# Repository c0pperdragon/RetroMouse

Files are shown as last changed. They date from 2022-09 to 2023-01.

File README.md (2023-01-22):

# RetroMouse
Adapter to attach PS/2 compatible mice to retro computers

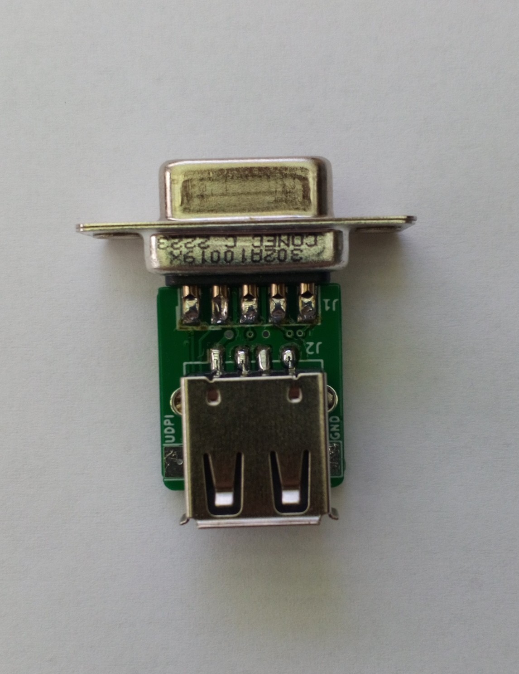
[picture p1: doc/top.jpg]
Top view


## Motivation

I wanted to try to make such an adapter using one attiny1604 microcontroller 
with only the minimum additional circuitry.
This part also was one of the few that mouser actually had in stock.

## Mouse compatibility

The USB socket suggests that any USB mouse can be used, but that is actually not true. In 
reality the adapter only supports the simpler PS/2 interface protocol which can be handled by
regular microcontrollers just well.

For this to work, the mouse must be able to optionally support PS/2 if needed. Luckily this
compatibility is present in quite many devices, especially in the cheap and simple variants.
Unluckily on the other hand, this compatibilty depends on the specific controller IC the
manufacturer used for the mouse and can not really be guessed from the outside.
When PS/2 compatibility is not directly advertised, the only thing to do is just try.

## Arduino development

The microcontroller is supported by the Arduino IDE (using the megaTinyCore add-on).
To modify the firmware, you need a programmer device to re-flash the microcontroller
using the UDPI pin. Details on this process are available on the megaTinyCore webpage.

## Compatibility

This adapter works with Amiga and C64 computers and can auto-detect the host machine.
Further machines (for example Atari ST) may be supported in the future. 

## C64 input modes

From power-up, the adapter emulates the Commodore 1351 mouse. If you want to 
emulate a pair of paddles instead (to play Arkanoid, for example) hold down the right mouse button 
and click the left button 5 times. Doing the same thing with 6 left clicks switches back
to standard mode.

## Attention! No Hot-Plugging

The adapter is not designed to be hot-plugged into the host machine or the mouse to be hot-plugged
into the adapter. Make sure to always power down the host when changing configuration.

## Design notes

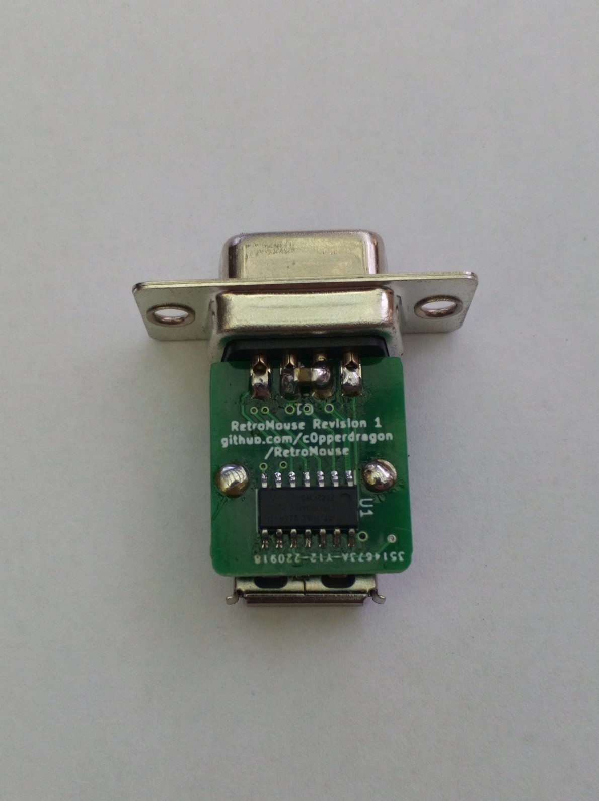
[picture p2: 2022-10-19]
doc/bottom.jpg

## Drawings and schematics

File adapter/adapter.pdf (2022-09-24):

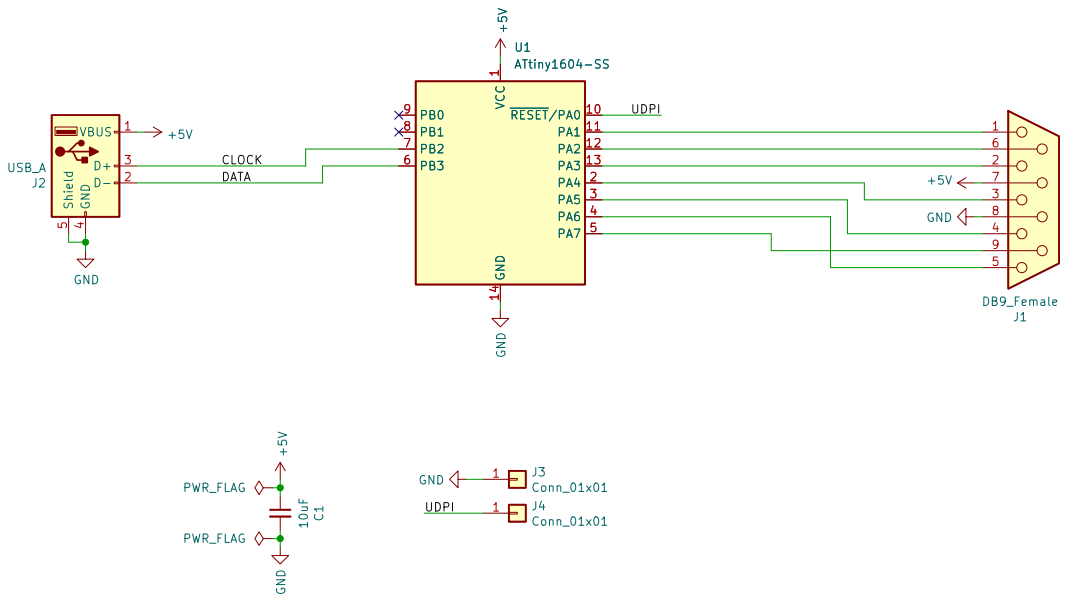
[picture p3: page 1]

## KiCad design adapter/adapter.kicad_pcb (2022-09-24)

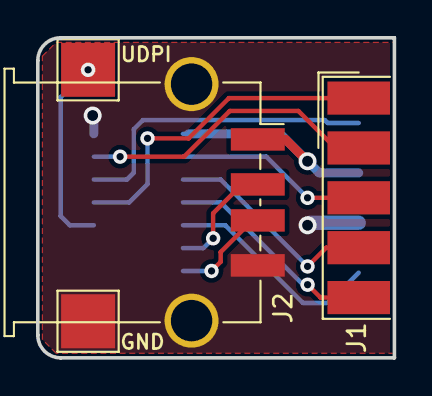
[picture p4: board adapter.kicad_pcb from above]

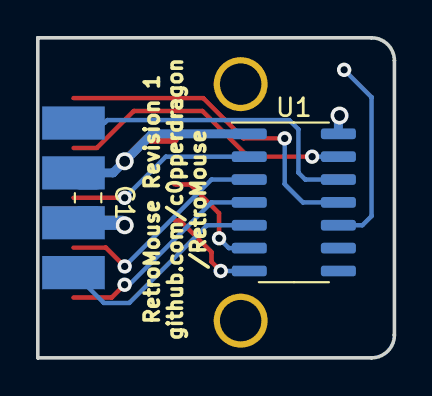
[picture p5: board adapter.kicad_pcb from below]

Board: 2 copper layers, 19.8 x 17.8 mm, 6 parts (2 on the bottom side), 12 nets.

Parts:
C1: 10uF; C_0805_2012Metric_Pad1.18x1.45mm_HandSolder
J1: DB9_Female; DSUB-9_Female_EdgeMount_P2.77mm
J2: USB_A; USB_A_TE_292303-7_Horizontal
J3, J4: Conn_01x01; TestPoint_Pad_3.0x3.0mm
U1: ATtiny1604-SS; SOIC-14_3.9x8.7mm_P1.27mm

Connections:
+5V: C1.1, J1.7, J2.1 (VBUS), U1.1 (VCC)
/CLOCK: J2.3 (D+), U1.7 (PB2)
/DATA: J2.2 (D-), U1.6 (PB3)
/UDPI: J4.1, U1.10 (~RESET/PA0)
GND: C1.2, J1.8, J2.4 (GND), J2.5 (Shield), J3.1, U1.14 (GND)
unnamed: J1.1, U1.11 (PA1)
unnamed: J1.2, U1.13 (PA3)
unnamed: J1.3, U1.2 (PA4)
unnamed: J1.4, U1.3 (PA5)
unnamed: J1.5, U1.4 (PA6)
unnamed: J1.6, U1.12 (PA2)
unnamed: J1.9, U1.5 (PA7)

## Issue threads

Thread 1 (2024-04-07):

How to build?

hjf, 2024-04-07:
Hello. I built the circuit like in the PDF file, and burned an attiny1614 (i don't have a 1604 but it seems it should still work).

I used megatinycore and set it to 16mhz, millis/micros disabled.

Unfortunately it doesn't seem to work when connected to a C64 with GEOS (configured for 1351 mouse). There is some random movement at times but it's completely random, the pointer is mostly still.

I've also downgraded megatinycore to 2.6.1 which was the latest version when this repo was updated but no luck either.

Am I missing something? I've checked the PS/2 lines and I don't see a constant stream of data, just some sporadic bursts of pulses. The mouse is a 1999 vintage Intellimouse Explorer which came with a USB to PS2 adapter so I know it should be compatible with PS2 (i've also tried other mice), so I'm thinking it could be related to build options.

c0pperdragon, 2024-04-07:
I don't remember much from the project any more. But finding a compatible mouse was actually quite a problem. I had best success with the cheapest USB mice as they seem to use quite an old PS2/USB compatible chip with just the bare minimum functionality. But it is really hit&miss there.

hjf, 2024-04-07:
OK, so I found an actual PS/2 mouse (Genius),... and it didn't work either.

So I tried changing the settings. It seems 8MHz is the right speed. I've noticed that the PS/2 lines have activity with this setting, but ONLY with the Intellimouse, not with the PS/2 mouse.

When connected to the C64, the mouse can click (WOO!!), but it doesn't move (aww). So I chased it to the upstream library for the mouse: https://github.com/getis/Arduino-PS2-Mouse-Handler/issues/1. The workaround in that issue didn't work for me either.

The TLDR of this is: may or may not work. Confirmed working is HP 600553-002 Optical Scrolling.

c0pperdragon, 2024-04-07:
For more troubleshooting you could try to power the adapter not from the C64 but directly from 5V (see schematics where to connect power). It would then go to Amiga mode when it does not detect the C64s polling. There you can better see on an oscilloscope what the mouse emulation intends to do.
The Amiga mouse directly puts the 2 signals of each of the 2 rotary decoders on 4 output pins. Also the mouse buttons are direcly available on the DSUB-9 connector:
X-Axis: pin 2 & pin 4
Y-Axis: pin 1 & pin 1
button 1-3: Pin  6, pin 5, pin 9

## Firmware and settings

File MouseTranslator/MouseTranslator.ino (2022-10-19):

// Target controller:  
//   attiny1604 with 16mhz
//   Disabled millis()/micros() to avoid timing glitches and free timer A
//   setup time 0 ms

#include "PS2MouseHandler.h"

#define DEBUG       PIN_PB1
#define MOUSE_DATA  PIN_PB3
#define MOUSE_CLOCK PIN_PB2
                                 // C64      Amiga mouse
#define SUBD_PIN1   PIN_PA1      // up       mouse v
#define SUBD_PIN2   PIN_PA3      // down     mouse h
#define SUBD_PIN3   PIN_PA4      // left     mouse vq
#define SUBD_PIN4   PIN_PA5      // right    mouse hq
#define SUBD_PIN5   PIN_PA6      // pot y    middle button
#define SUBD_PIN6   PIN_PA2      // button   left buttonm
#define SUBD_PIN9   PIN_PA7      // pot x    right button

#define MODE_AMIGA    1
#define MODE_C64      2
#define MODE_ATARI    3
byte mode;

PS2MouseHandler mouse(MOUSE_CLOCK, MOUSE_DATA);
unsigned int x;
unsigned int y;



// ------ low-level subd pin handling ---------
bool countedges;
unsigned int edgecounter;
unsigned int edgeseparation;

// set pin to either low (when active) or having a weak pullup
void set_subd(byte pin, bool active)
{
    if (active) 
    {
        digitalWrite(pin, LOW);  
        pinMode(pin, OUTPUT);
    }
    else
    {
        pinMode(pin, INPUT_PULLUP);
    }
}
void init_subd(bool emulate_pots, bool count)
{
    set_subd(SUBD_PIN1, false);
    set_subd(SUBD_PIN2, false);
    set_subd(SUBD_PIN3, false);
    set_subd(SUBD_PIN4, false);
    set_subd(SUBD_PIN5, false);
    set_subd(SUBD_PIN6, false);
    set_subd(SUBD_PIN9, false);
    AC0.INTCTRL = 0x00;          // disable AC interrupt       
    TCA0.SINGLE.INTCTRL = 0x00;  // disable TCA0 interrupts

    TCA0.SINGLE.CTRLA = 0x01;          // enable timer at full speed
    TCA0.SINGLE.CTRLB = 0x00;          // normal counting mode
    TCA0.SINGLE.CTRLC = 0x00;          // no timer output on pins
    TCA0.SINGLE.CTRLD = 0x00;          // disable split mode (use single mode)
    TCA0.SINGLE.CTRLECLR = 0x03;       // normal register update, counting up
    TCA0.SINGLE.EVCTRL = 0x00;         // no event couting                
    TCA0.SINGLE.CNT = 0;
    TCA0.SINGLE.PER = 0xffff;
    TCA0.SINGLE.CMP0 = 0xffff;
    TCA0.SINGLE.CMP1 = 0xffff;
    if (emulate_pots)
    {
        countedges = false;        
        TCA0.SINGLE.INTCTRL = 0x30;        // enable compare interrupt on cannels 0 & 1 
    }
    else if (count)
    {
        countedges = true;
    }
    if (emulate_pots || count)
    {
        VREF.CTRLA = 0x00;         // use 0.55V as VREF for the AC
        AC0.MUXCTRLA = 0x02;       // compare PA7 against voltage reference
        AC0.CTRLA = 0x27;          // trigger at negative edge, maximum hysteresis
        AC0.INTCTRL = 0x01;        // enable AC interrupt 
    }    
}
void set_pots(unsigned int x, unsigned int y)
{
    TCA0.SINGLE.CMP0BUF = x;
    TCA0.SINGLE.CMP1BUF = y;
}
// triggered when PA7 (PIN_SUBD9) goes low 
ISR (AC0_AC_vect) 
{
    if (countedges) 
    { 
        unsigned int c = TCA0.SINGLE.CNT; // read counter value to determine period length
        TCA0.SINGLE.CTRLESET = 0x08;      // command to restart the counter
        c = c+100;                         // fine-tuned
        if (c>7000 && c<9000) // check for plausibility
        {   // slowly adjust detected period
            if (c<edgeseparation-10) { edgeseparation-=3; }
            else if (c<edgeseparation) { edgeseparation--; }
            else if (c>edgeseparation+10) { edgeseparation+=3; }
            else if (c>edgeseparation) { edgeseparation++; }
        }
        edgecounter++; 
    } 
    else
    {
        // turn off pull-ups and trigger timer to later re-enable them
        PORTA.PIN7CTRL = 0x00;    // disable pull.up
        PORTA.PIN6CTRL = 0x00;    // disable pull-up
        TCA0.SINGLE.CTRLESET = 0x08;  // command to restart the counter
        TCA0.SINGLE.CTRLESET = 0x04;  // command to update values from buffers        
    }        
    AC0.STATUS = 0x01;        // clear interrupt flag
}
// triggerd when pull-up for potx should be activated
//ISR (TCA0_CMP0_vect) 
//{
//    TCA0.SINGLE.INTFLAGS = 0x10;   // clear interrupt flag 
//    PORTA.PIN7CTRL = 0x08;         // enable pull.up
//}
ISR (TCA0_CMP0_vect, ISR_NAKED ) {
    asm ( 
         "push r24          \n"  
         "ldi  r24, 0x10    \n"  
         "sts  0x0a0b, r24  \n"
         "ldi  r24, 0x08    \n"
         "sts  0x0417, r24  \n"
         "pop  r24          \n"
         "reti              \n"
    );
}
// triggerd when pull-up for poty should be activated
//ISR (TCA0_CMP1_vect) 
//{
//    TCA0.SINGLE.INTFLAGS = 0x20;   // clear interrupt flag 
//    PORTA.PIN6CTRL = 0x08;         // enable pull-up
//}
ISR (TCA0_CMP1_vect, ISR_NAKED ) {
    asm ( 
         "push r24          \n"  
         "ldi  r24, 0x20    \n"  
         "sts  0x0a0b, r24  \n"
         "ldi  r24, 0x08    \n"
         "sts  0x0416, r24  \n"
         "pop  r24          \n"
         "reti              \n"
    );
}


unsigned int amiga_x;
unsigned int amiga_y;

void init_amiga()
{
    init_subd(false,false);
    amiga_x = 0;
    amiga_y = 0;
}

void run_amiga()
{
    unsigned int newx = x >> 2;
    unsigned int newy = y >> 2;
    set_subd(SUBD_PIN6, mouse.button(0)!=0);
    set_subd(SUBD_PIN5, mouse.button(1)!=0);
    set_subd(SUBD_PIN9, mouse.button(2)!=0);
    while ((amiga_x != newx) || (amiga_y != newy))
    {
        if (amiga_x != newx)
        {
            if (mouse.x_movement()<0) { amiga_x = (amiga_x - 1) & 0x3fff; }
            else                      { amiga_x = (amiga_x + 1) & 0x3fff; }
            set_subd(SUBD_PIN2, (amiga_x&0x2) != 0);
            set_subd(SUBD_PIN4, ((amiga_x-1)&0x2) != 0);
        }
    
        if (amiga_y != newy)
        {
            if (mouse.y_movement()<0) { amiga_y = (amiga_y - 1) & 0x3fff; }
            else                      { amiga_y = (amiga_y + 1) & 0x3fff; }
            set_subd(SUBD_PIN1, (amiga_y&0x2) != 0);
            set_subd(SUBD_PIN3, ((amiga_y+1)&0x2) != 0);
        }
        delayMicroseconds(50);
    }
}


#define C64MOUSEMIN 5000
unsigned int c64_mousespan; 

#define C64PADDLEMIN 3900
#define C64PADDLEMAX 7750

bool c64_usepaddles;
int c64_prevleftbutton;
int c64_countclicks;

void init_c64()
{
    init_subd(true,false);
    c64_usepaddles = false;
}

void run_c64()
{
    if (c64_usepaddles)
    {
        set_subd(SUBD_PIN1, mouse.button(2)!=0);
        set_subd(SUBD_PIN3, mouse.button(0)!=0);
        set_subd(SUBD_PIN6, false);
        if (x<C64PADDLEMIN) { x = C64PADDLEMIN; }
        if (x>C64PADDLEMAX) { x = C64PADDLEMAX; }
        if (y<C64PADDLEMIN) { y = C64PADDLEMIN; }
        if (y>C64PADDLEMAX) { y = C64PADDLEMAX; }
        set_pots(C64PADDLEMAX-(x-C64PADDLEMIN),y);
    }
    else
    {
        set_subd(SUBD_PIN1, mouse.button(2)!=0);
        set_subd(SUBD_PIN3, false);
        set_subd(SUBD_PIN6, mouse.button(0)!=0);
        long scalex = x & 0x1ff;
        long scaley = y & 0x1ff;
        scalex = (scalex * (c64_mousespan)) >> 9;
        scaley = (scaley * (c64_mousespan)) >> 9;
        set_pots(C64MOUSEMIN+(int)scalex, C64MOUSEMIN+(int)scaley);
    }
    // handle manual c64 mode switching
    if (mouse.button(2)!=0)   // while holding right mouse button 
    {
        if (mouse.button(0)!=0 && c64_prevleftbutton==0) { c64_countclicks++; }      
    }
    else                      // after releasing right mouse button
    {
        if (c64_countclicks==5) { c64_usepaddles = true; }        
        if (c64_countclicks==6) { c64_usepaddles = false; }
        c64_countclicks = 0;
    }
    c64_prevleftbutton = mouse.button(0);
}


void init_atari()
{
    init_subd(false,false);
}

void run_atari()
{
    set_subd(SUBD_PIN1, mouse.button(2)!=0);
    set_subd(SUBD_PIN3, mouse.button(0)!=0);
    set_subd(SUBD_PIN6, false);

    // TODO: paddle emulation
}

void detect_mode()
{
    edgecounter = 0;
    edgeseparation = 8192;  // first estimate of scan interval (in arduino clocks) 

    init_subd(false,true);
    delay(500);
    init_subd(false,false);
    pinMode(SUBD_PIN9, INPUT);
    delay(500);
    
    if (edgecounter>500) 
    { 
        mode=MODE_C64; 
        c64_mousespan = edgeseparation / 4;
    }
    else 
    { 
        mode=MODE_AMIGA; 
    }    
}


void setup()
{   
    // debugging pin
    pinMode(DEBUG, OUTPUT);    
    digitalWrite(DEBUG, LOW);
    
    // quickly turn on pull-ups to allow mouse to auto-detect PS/2 mode
    pinMode(MOUSE_DATA, INPUT_PULLUP); 
    pinMode(MOUSE_CLOCK, INPUT_PULLUP);

    detect_mode();
    switch (mode)
    {
        case MODE_AMIGA:  init_amiga();   break;
        case MODE_C64:    init_c64();     break;
        case MODE_ATARI:  init_atari();  break;
    }     
}

void loop()
{
    if (mouse.initialise()!=0) { return; }
    x = 0;
    y = 0;
         
    for (;;)
    {
        if (mouse.get_data()!=0) { return; }
        x = x + (unsigned int) mouse.x_movement();
        y = y + (unsigned int) mouse.y_movement();     

        switch (mode)
        {
            case MODE_AMIGA:  run_amiga();  break;
            case MODE_C64:    run_c64();    break;
            case MODE_ATARI:  run_atari(); break;
        }    
    }
}
 

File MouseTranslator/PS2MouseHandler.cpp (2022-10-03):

#include <Arduino.h>

#include "PS2MouseHandler.h"

PS2MouseHandler::PS2MouseHandler(int clock_pin, int data_pin, int mode) {
  _clock_pin = clock_pin;
  _data_pin = data_pin;
  _mode = mode;
  _initialised = false;
  _disabled = true;
  _enabled = false;
  _device_id = 0x00;
  _no_mouse = false;
  _last_status = 0; // will hold copy of status byte
}

int PS2MouseHandler::clock_pin() {
  return _clock_pin;
}

int PS2MouseHandler::data_pin() {
  return _data_pin;
}

int PS2MouseHandler::device_id () {
  return _device_id;
}

int PS2MouseHandler::status () {
  return _status;
}

int PS2MouseHandler::x_movement () {
  return _x_movement;
}

int PS2MouseHandler::y_movement () {
  return _y_movement;
}

int PS2MouseHandler::z_movement () {
  return _z_movement;
}

bool PS2MouseHandler::button(int button_num){
  return (bool)( _status & get_button_mask(button_num));
}

bool PS2MouseHandler::clicked(int button_num){
  if (button(button_num) && !(bool)( _last_status & get_button_mask(button_num))) {
    return true;
  }
  else {
    return false;
  }
}

uint8_t PS2MouseHandler::get_button_mask(int button){
  uint8_t mask = 0;
  switch(button){
    case 0: // left
      mask = 0x01;
      break;
    case 1: // middle
      mask = 0x04;
      break;
    case 2: // right
      mask = 0x02;
      break;
    default:
      mask = 0;
      break;
  }
  return mask;
}

int PS2MouseHandler::initialise() {

  int counter = 0;
  int return_value = 0;
  // poll mouse to get a connection
  do {
    return_value = try_initialise();
    counter ++;
  } while ((return_value != 0) && (counter < 10));
  return return_value;
}

int PS2MouseHandler::try_initialise() {
  pull_high(_clock_pin); // idle state
  pull_high(_data_pin);
  write(0xff); // Send Reset to the mouse
  if (_no_mouse){
    return 100; // no mouse
  }
  uint8_t bat_code = read_byte();  // Read BAT completion code
  if (bat_code == 0xFC){ // error?
    _no_mouse = true;
    return 101; // BAT failed
  }
  read_byte();  // Device ID - ignore for now - should be 0x00 for mouse

  // set scroll wheel mode if available
  set_sample_rate(200, true);
  set_sample_rate(100, true);
  set_sample_rate(80, true);
  _device_id = get_device_id(); // 0x00 = no scroll wheel

  if (_mode == PS2_MOUSE_REMOTE) {
    set_remote_mode();
  } else {
    enable_data_reporting(); // Tell the mouse to start sending data again
  }
  delayMicroseconds(100);
  _initialised = 1;
  get_data(); // initial read of mouse data
  _last_status = _status; // suppress false button presses
  return 0; // OK
}

void PS2MouseHandler::set_mode(int data) {
  if (_mode == PS2_MOUSE_STREAM) {
    disable_data_reporting(); // Tell the mouse to stop sending data.
  }
  write(data);  // Send Set Mode
  read_byte();  // Read Ack byte
  if (_mode == PS2_MOUSE_STREAM) {
    enable_data_reporting(); // Tell the mouse to start sending data again
  }
  if (_initialised) {
    delayMicroseconds(100);
  }
}

int PS2MouseHandler:: get_device_id(){
  write(0xf2); // Ask mouse for device ID.
  int id =  read_byte(); // Read first byte - gives overall device id
  read_byte(); // try to read second byte if sent - refines device type - not needed
  return id;
}

void PS2MouseHandler::set_remote_mode() {
  set_mode(0xf0);
  _mode = PS2_MOUSE_REMOTE;
}

void PS2MouseHandler::set_stream_mode() {
  set_mode(0xea);
  _mode = PS2_MOUSE_STREAM;
}

void PS2MouseHandler::set_sample_rate(int rate, bool ignore_sample_rate) {
  if (_mode == PS2_MOUSE_STREAM && !ignore_sample_rate) {
    disable_data_reporting(); // Tell the mouse to stop sending data.
  }
  write(0xf3); // Tell the mouse we are going to set the sample rate.
  read_byte(); // Read Ack Byte
  write(rate); // Send Set Sample Rate
  read_byte(); // Read ack byte
  if (_mode == PS2_MOUSE_STREAM && !ignore_sample_rate) {
    enable_data_reporting(); // Tell the mouse to start sending data again
  }
  delayMicroseconds(100);
}

void PS2MouseHandler::set_scaling_2_1() {
  set_mode(0xe7); // Set the scaling to 2:1
}

void PS2MouseHandler::set_scaling_1_1() {
  set_mode(0xe6); // set the scaling to 1:1
}

// This only effects data reporting in Stream mode.
void PS2MouseHandler::enable_data_reporting() {
  if (!_enabled) {
    write(0xf4); // Send enable data reporting
    read_byte(); // Read Ack Byte
    _enabled = true;
  }
}

// Disabling data reporting in Stream Mode will make it behave like Remote Mode
void PS2MouseHandler::disable_data_reporting() {
  if (!_disabled) {
    write(0xf5); // Send disable data reporting
    read_byte(); // Read Ack Byte
    _disabled = true;
  }
}

void PS2MouseHandler::set_resolution(int resolution) {
  if (_mode == PS2_MOUSE_STREAM) {
    enable_data_reporting();
  }
  write(0xe8); // Send Set Resolution
  read_byte(); // Read ack Byte
  write(resolution); // Send resolution setting
  read_byte(); // Read ack Byte
  if (_mode == PS2_MOUSE_STREAM) {
    disable_data_reporting();
  }
  delayMicroseconds(100);
}

void PS2MouseHandler::write(int data) {
  char i;
  char parity = 1;
  pull_high(_data_pin);
  pull_high(_clock_pin);
  delayMicroseconds(300);
  pull_low(_clock_pin);
  delayMicroseconds(300);
  pull_low(_data_pin);
  delayMicroseconds(10);
  pull_high(_clock_pin); // Start Bit
  // wait for mouse to take control of clock
  if (!wait_for_pin(_clock_pin, LOW, 30000)) {
      // no connection to mouse
      pull_high(_data_pin); // back to waiting
      _no_mouse = true;
      return;
  } 
  _no_mouse = false; // connection to mouse OK
  // clock is low, and we are clear to send data
  for (i=0; i < 8; i++) {
    if (data & 0x01) {
      pull_high(_data_pin);
    } else {
      pull_low(_data_pin);
    }
    // wait for clock cycle
    wait_for_pin(_clock_pin, HIGH, 1000); // while (!digitalRead(_clock_pin)) {;}
    wait_for_pin(_clock_pin, LOW, 1000);  // while (digitalRead(_clock_pin)) {;}
    parity = parity ^ (data & 0x01);
    data = data >> 1;
  }
  // parity
  if (parity) {
    pull_high(_data_pin);
  } else {
    pull_low(_data_pin);
  }
  // wait for clock cycle
  wait_for_pin(_clock_pin, HIGH, 1000); // while (!digitalRead(_clock_pin)) {;}
  wait_for_pin(_clock_pin, LOW, 1000);  // while (digitalRead(_clock_pin)) {;}
  pull_high(_data_pin); // release data line
  wait_for_pin(_data_pin, LOW, 1000);   // while (digitalRead(_data_pin)) {;} // wait for mouse to take over data line
  wait_for_pin(_clock_pin, LOW, 1000);  // while (digitalRead(_clock_pin)) {;} // wait for mouse to take over clock
  wait_for_pin(_data_pin, HIGH, 1000); wait_for_pin(_clock_pin, HIGH, 1000);  // while ((!digitalRead(_clock_pin)) && (!digitalRead(_data_pin))) {;} // wait for mouse to release clock and data
}

void PS2MouseHandler::hold_incoming_data(){
  pull_low(_clock_pin);
}
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

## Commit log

2022-09-08 Reduce timing jitter caused by interrupts
    [MouseTranslator.ino, PS2MouseHandler.cpp]
2022-09-24 Design PCB and adjust code
    [adapter.kicad_pcb, adapter.kicad_sch, adapter.sch]
2022-10-03 Autodetect machine. Manual C64 mode switching.
2022-10-12 Fail to support atari paddles.
    [MouseTranslator.ino]
2023-01-22 Add warning to not hot-plug the device.
